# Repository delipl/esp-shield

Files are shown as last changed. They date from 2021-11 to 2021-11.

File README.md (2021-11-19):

# esp-shield
Shield for Arduino Uno to upload and communicate with ESP-01 and ESP-12E.
# Features
- programmable ESP
- soft serial for arduino
- jumper between RX TX frmm Arduino and ESP for programming mode and communication
- extruded ESP-12E pinout

# 3D model photos
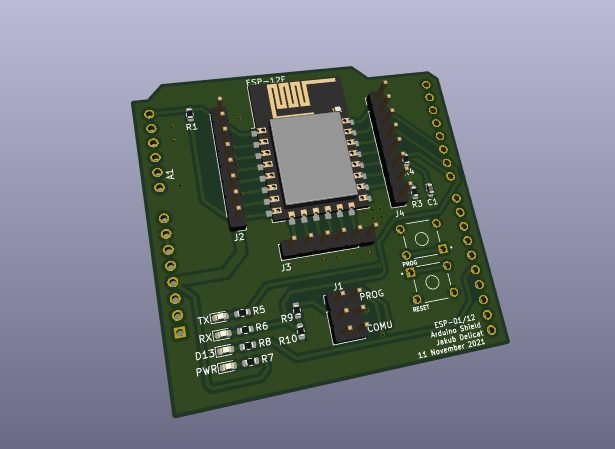
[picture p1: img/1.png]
First screenshot

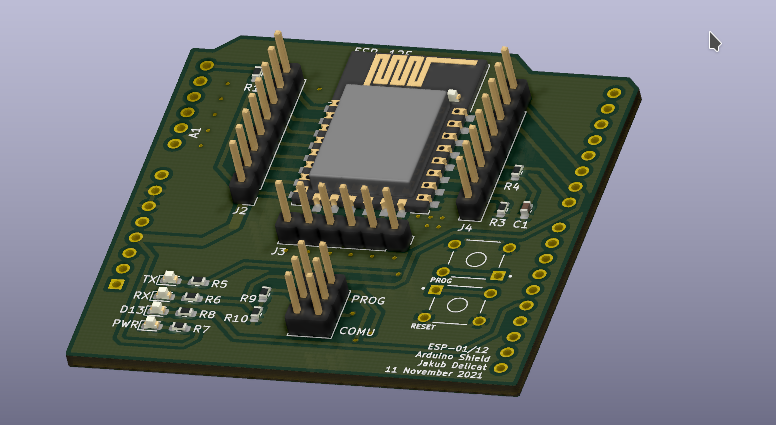
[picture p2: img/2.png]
Second screenshot


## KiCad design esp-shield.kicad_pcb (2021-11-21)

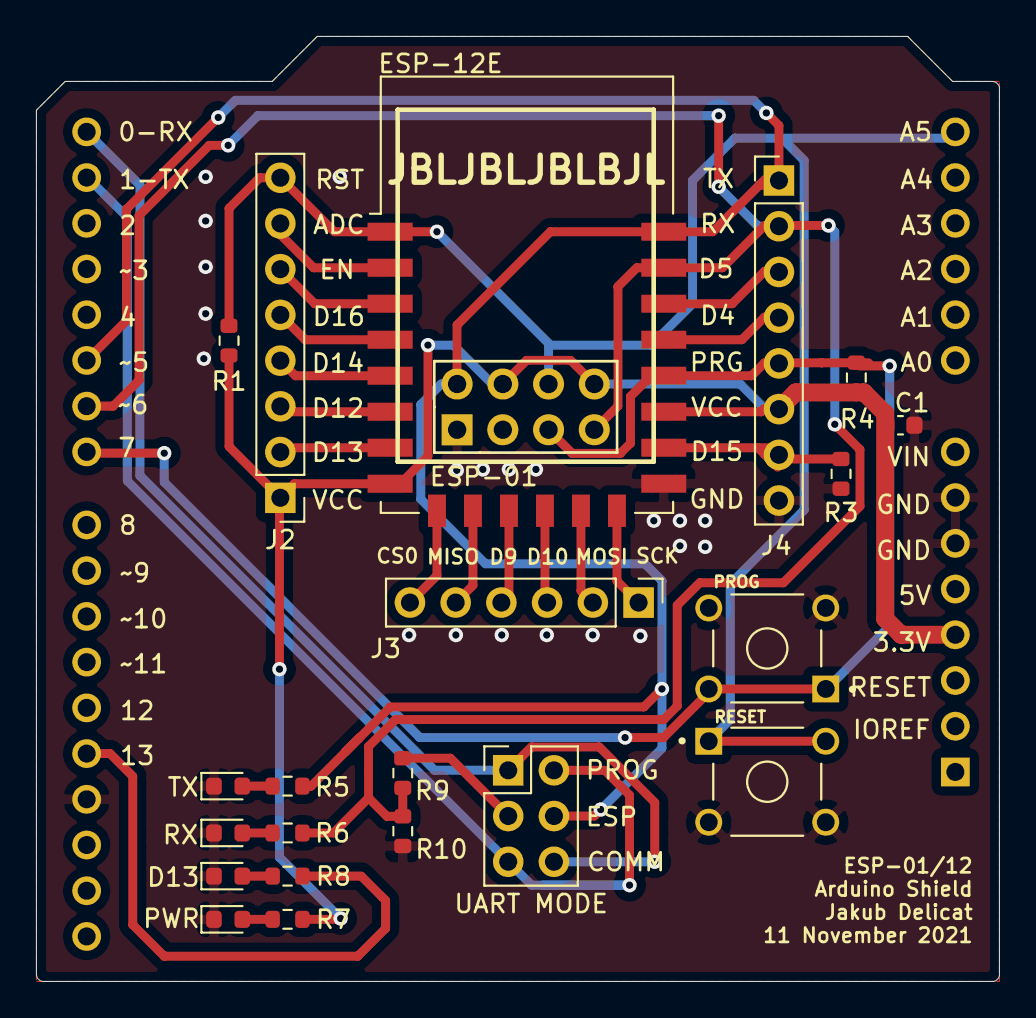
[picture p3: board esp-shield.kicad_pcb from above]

Board: 2 copper layers, 53.5 x 52.5 mm, 23 parts (1 on the bottom side), 29 nets.

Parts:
A1: Arduino_UNO_R3
BUILTIN1: D13; LED_0603_1608Metric
C1: C; C_0603_1608Metric
D1: TX; LED_0603_1608Metric
ESP-12E1: ESP-12E
J1: UART MODE; PinHeader_2x03_P2.54mm_Vertical
J2, J4: Conn_01x08; PinHeader_1x08_P2.54mm_Vertical
J3: Conn_01x06; PinHeader_1x06_P2.54mm_Vertical
PWR1: PWR; LED_0603_1608Metric
R1, R3, R4: 10kOhm; R_0603_1608Metric
R5, R6, R7, R8: R; R_0603_1608Metric
R9: 1kOhm; R_0603_1608Metric
R10: 2k2OHM; R_0603_1608Metric
RX1: RX; LED_0603_1608Metric
SW1: RESET; TE_1-1825910-4
SW2: PROG; TE_1-1825910-4
U2: ESP-01

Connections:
/RX_AR: A1.15, J1.1, J1.6
/TX_AR: A1.16, J1.2, J1.5
ADC: ESP-12E1.2, J2.7
CS0: ESP-12E1.9, J3.6
D13: A1.28, R8.1
EN: ESP-12E1.3, J2.6
GND: A1.6, A1.7, A1.29, BUILTIN1.1, C1.2, D1.1, ESP-12E1.15, J4.8, PWR1.1, R3.2, R10.1, RX1.1, SW1.3, SW1.4, SW2.3, SW2.4, U2.1
GPIO4: ESP-12E1.19, J4.4
GPIO5: ESP-12E1.20, J4.3
GPIO9: ESP-12E1.11, J3.4
GPIO10: ESP-12E1.12, J3.3
GPIO12: ESP-12E1.6, J2.3
GPIO13: ESP-12E1.7, J2.2
GPIO14: ESP-12E1.5, J2.4
GPIO15: ESP-12E1.16, J4.7, R3.1
GPIO16: ESP-12E1.4, J2.5
MISO: ESP-12E1.10, J3.5
MOSI: ESP-12E1.13, J3.2
unnamed: BUILTIN1.2, R8.2
unnamed: D1.2, R5.2
unnamed: PWR1.2, R7.2
unnamed: R6.2, RX1.2
PROG: A1.22, ESP-12E1.18, J4.5, R4.2, SW2.1, SW2.2, U2.3
RST: A1.14, ESP-12E1.1, J2.8, R1.2, SW1.1, SW1.2, U2.7
RX_PROG: A1.21, ESP-12E1.21, J4.2, R6.1, R9.1, R10.2, U2.4
RX_PROG5V: J1.3, R9.2
SCLK: ESP-12E1.14, J3.1
TX_PROG: A1.20, ESP-12E1.22, J1.4, J4.1, R5.1, U2.5
VCC: A1.4, C1.1, ESP-12E1.8, ESP-12E1.17, J2.1, J4.6, R1.1, R4.1, R7.1, U2.6, U2.8

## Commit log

2021-11-19 Project ready for order
    [esp-shield.kicad_pcb, esp-shield.sch]
2021-11-19 Push unsaved things
    [esp-shield.sch]
2021-11-20 Added esp112E labeling
    [esp-shield.kicad_pcb]
2021-11-21 Added Arduino pinout labels
    [esp-shield.kicad_pcb, esp-shield.sch]
2021-11-21 FLipped arduino xD
    [esp-shield.kicad_pcb]
2021-11-21 ADDED JP ASD
    [esp-shield.kicad_pcb]
